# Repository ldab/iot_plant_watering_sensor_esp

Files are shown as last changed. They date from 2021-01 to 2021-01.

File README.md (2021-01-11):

# iot_plant_watering_sensor_esp32
Connected, IoT, WiFi capacitance plant watering sensor based on ESP32







 ## TODO

- [ ] Better battery polarity indication and reverse polarity protection;
- [ ] Fix R16 - R19 Silk
- [ ] R15 is leaking 200uA
- [ ] Check if `esp_light_sleep_start()` improves current vs `delay(x)`
- [ ] Inspect connection time if BSSID is saved vs Saving time
- [ ] FOTA
- [ ] Error reporting and callbacks, i.e FFAT, ADC read, etc..

## VOID

"Lorem ipsum dolor sit amet, consectetur adipiscing elit, sed do eiusmod tempor incididunt ut labore et dolore magna aliqua. Ut enim ad minim veniam, quis nostrud exercitation ullamco laboris nisi ut aliquip ex ea commodo consequat. Duis aute irure dolor in reprehenderit in voluptate velit esse cillum dolore eu fugiat nulla pariatur. Excepteur sint occaecat cupidatat non proident, sunt in culpa qui officia deserunt mollit anim id est laborum."

## Working modes and button

* The device will check the moisture 2x a day, at 8am and 6pm;
* On Sundays it will connect to the internet and check time, etc;
* Insert the battery **WATCH THE POLAITY**;
* Press and hold the `config` button;
  * keep it pressed, it will connect to the internet, get the time and date and calibrate the sensor;
  * if everything goes well, it buzzes like this [link for audio]()
* If the battery voltage is lower than 2V, an `email` will be sent and it buzzes like this [link for audio](./ringtones/urgent.mid)
* If the soil is drier than the setpoint, an `email` will be sent and it buzzes like this [link for audio]()
* If a new level of alarm is nedded, press and hold the config button until a buzz like this [link for audio]() is heard;

## Component selection and Capacitive probe

* We need the most range on the voltage across the probe as possible, considering
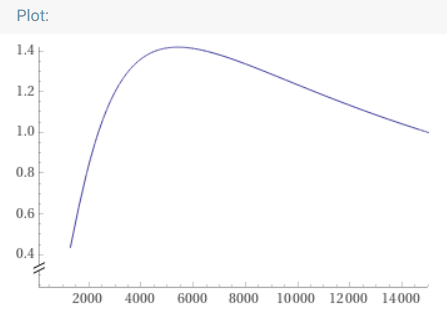
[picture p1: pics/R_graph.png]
    
    
**`Vc = 3 * (1 - e(-t / (R * C)))`**

* Varying R from 100 to 15000 Ω @ 1MHz:



[Wolfram Alpha - R Graph](https://www.wolframalpha.com/input/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)

* From the graph below we go with 5KΩ, the capacitance of the probe varies from 50pF to 200pF:

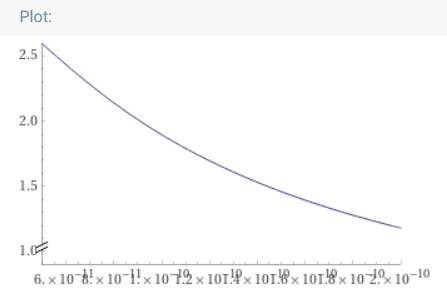
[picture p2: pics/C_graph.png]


[Wolfram Alpha - C Graph](https://www.wolframalpha.com/input/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)

* With a voltage range of 2.6 to 1.2 **~1.4V**.

## Capacitive sensor measurement

* When in the air, the sensor measures ~2.67V @ 1666(adc)



* And below 1000 (adc) ~1.8V when wet soil/water



## PSEUDO-CODE

```
main()
{ 
  turn radio OFF;
  config pins;

  read RTC();

  if( dateIsNotSet )    // probably first time
  {
    beep 2x;
    connect to the internet;
    set date;
    config RTC;
  }

  read moisture;

  if( alarmIsNotActive ) // wake from button
  {
    beep 5x;
    set new moisture level;
    clear alarm flag;    // aka sleep
  }
  else
  {
    if( moisture < threshould)
    {
      connect to the internet;
      send email/MQTT;
      turn radio OFF;

      while( times )
      {
        chrip
      }

      wake 
      clear alarm flag;    // aka sleep
    }
    else
    {
      clear alarm flag;    // aka sleep
    }
  }

  printf should never get here
} 
```

## Power Profile

* The DHCP negotiation and IP assignment can take a long time depending on the router, the below example is from a fairly long avg 90mA@2.8V for 3 s -> Includes ADC reading and MQTT publish

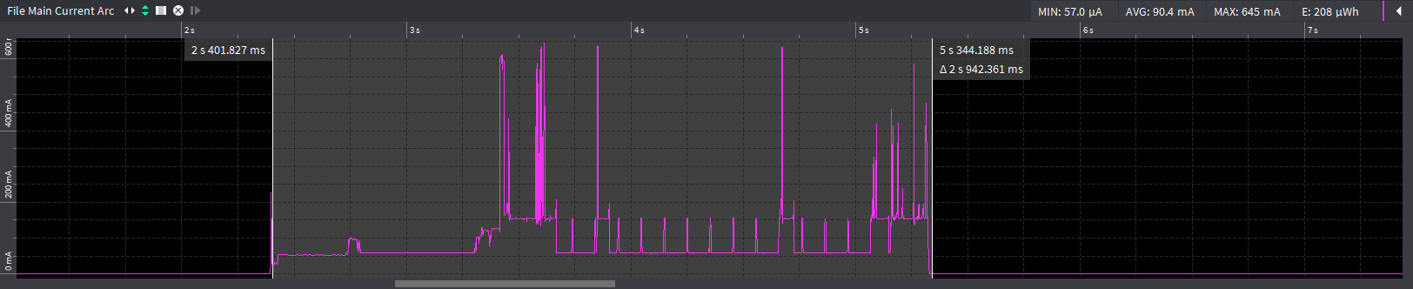
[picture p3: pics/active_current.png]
 

* When not connecting to WiFi, it is a lot faster:

 

* And during sleep 6uA@2.8V maninly due to the battery ADC (VCC/1MOhm =~ 3uA) and Boost disabled, ~1uA

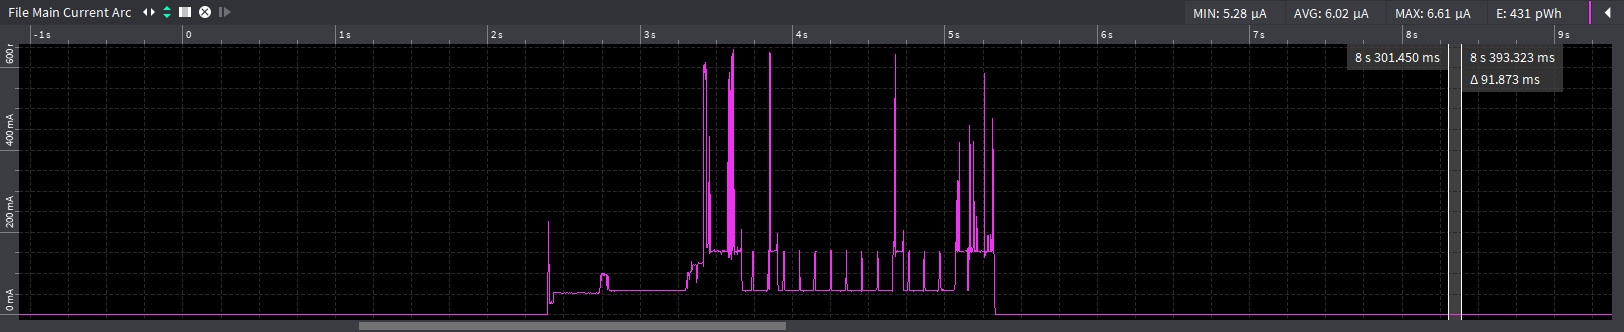
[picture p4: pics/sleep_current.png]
 

* Primary battery CR-2 drops a bit during active, 280mv:

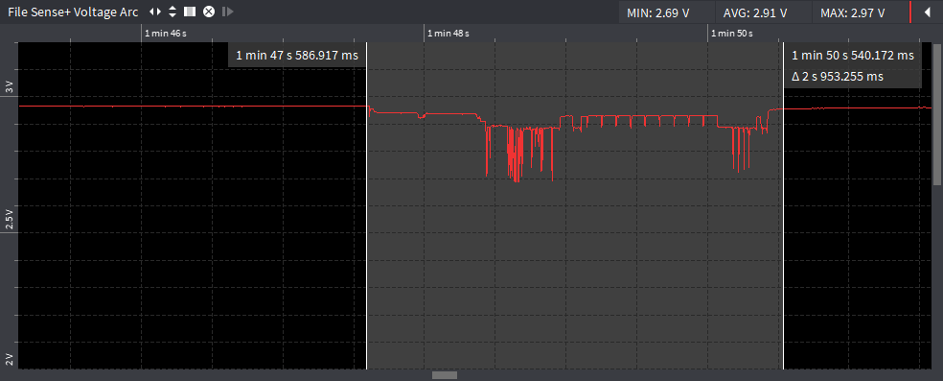
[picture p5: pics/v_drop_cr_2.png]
 

## Calibrating ADC for ESP32

* ADC on ESP32 has been reported being innacurate, therefore one can use ```adc2_vref_to_gpio( GPIO_NUM_25 );``` to route `Vref` to `GPIO_NUM_25` that can be measured over `ESP32 pin 10` in order to calibrate during ADC measurement.
* Calling for `esp_adc_cal_characterize(ADC_UNIT_1, ADC_ATTEN_DB_6, ADC_WIDTH_BIT_11, Vref, adc_chars);`

https://docs.espressif.com/projects/esp-idf/zh_CN/latest/esp32/api-reference/peripherals/adc.html

## FFat and time

```
  [641] IP address: 192.168.0.22
  Contacting Time Server
  [854] Now is : 2020-11-27T16:37:33
  Writing file: /hello.txt
  File written
  [1030] DONE writing, took: 176ms
  Reading file: /hello.txt
  Read from file: 2020-11-27T16:37:33
  [1093] DONE reading, took: 5ms
```

## Schematic

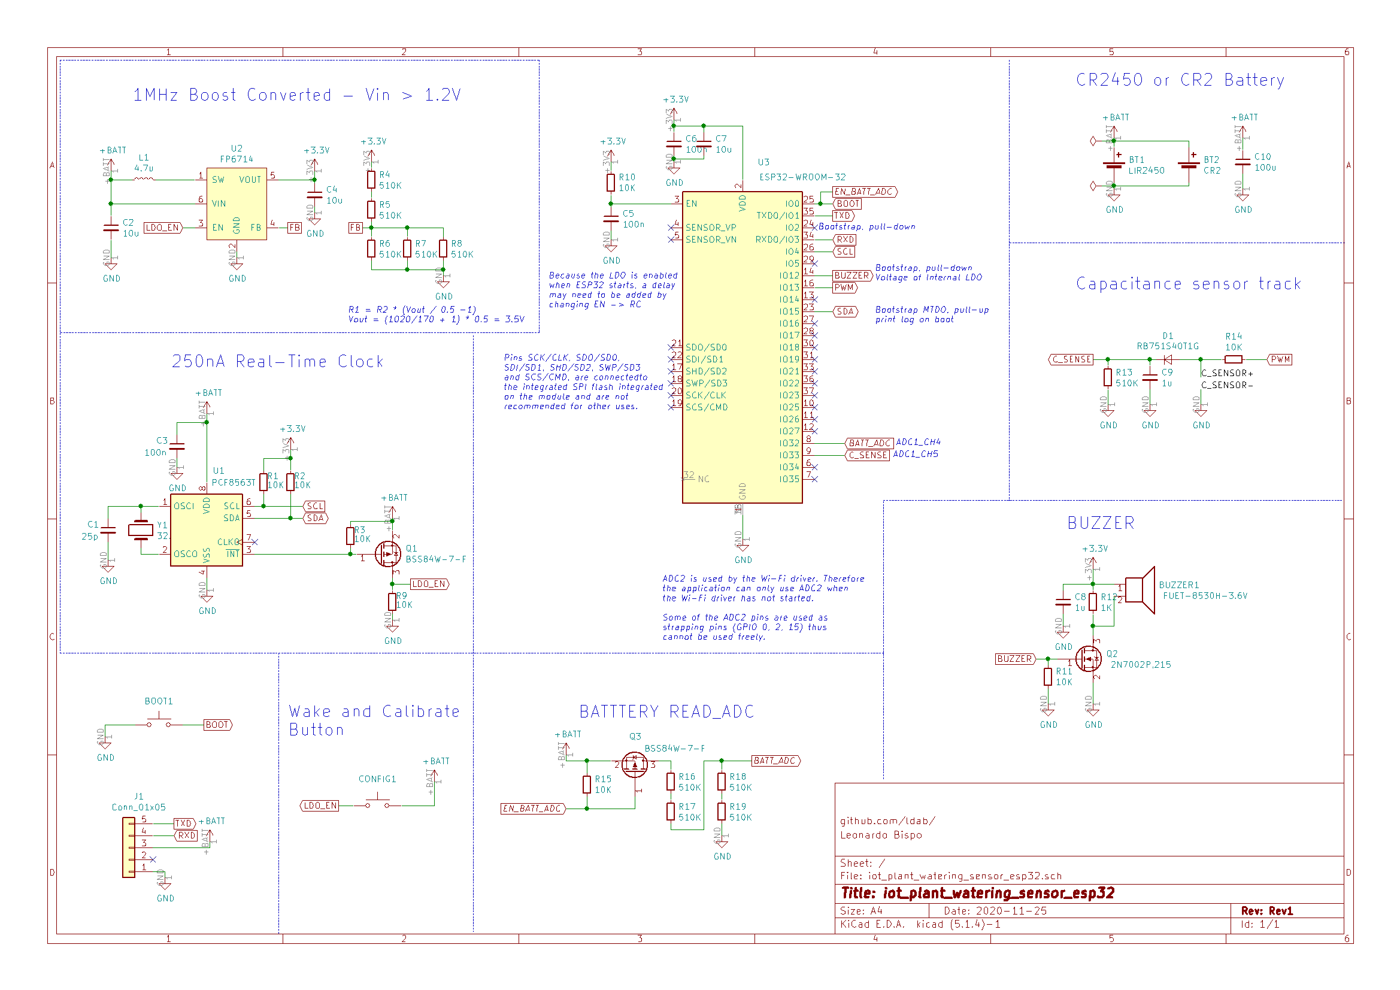
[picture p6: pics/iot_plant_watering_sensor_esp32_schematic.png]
 

## PCB

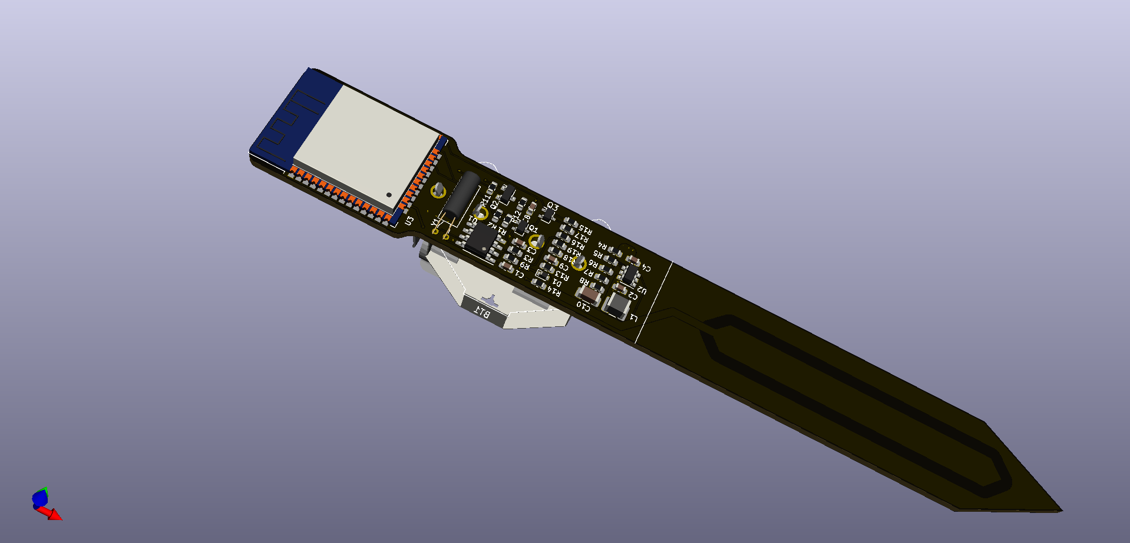
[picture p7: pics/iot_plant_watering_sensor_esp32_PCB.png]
 

## Enclosure

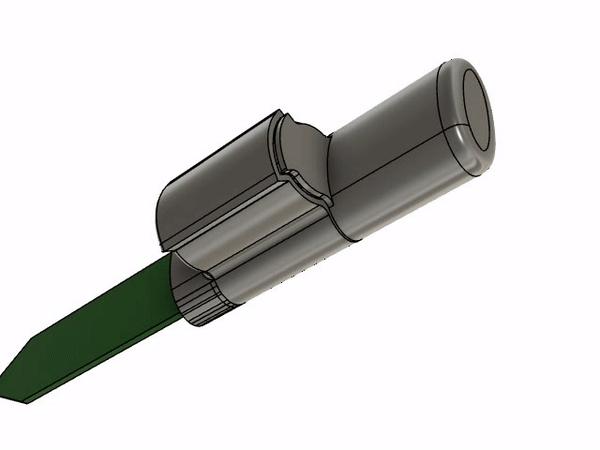
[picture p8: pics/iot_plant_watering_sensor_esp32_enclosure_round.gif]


## Known Limitations

* 

## Credits

Github Shields and Badges created with [Shields.io](https://github.com/badges/shields/)

Inspired by [chirp! - the plant watering alarm](https://wemakethings.net/chirp/)

ESP32 Pin definition and overview https://randomnerdtutorials.com/esp32-pinout-reference-gpios/

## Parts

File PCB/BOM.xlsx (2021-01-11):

Quantity | Description(optional) | LCSC Part Number(optional) | Package(optional) | Customer Part Number(optional)
2 | Push button switch, generic, two pins | C128941 | SamacSys_Parts:SW_Push_1P1T_NO_CK_KMR2 | > BOOT1, CONFIG1
1 | Single-cell battery | C238100 | Battery:BatteryHolder_Keystone_3008_1x2450 | BT1
1 | Single-cell battery | C238092 | custom:2915_CR2 | BT2
1 | Speaker | C417429 | Buzzer_Beeper:PUIAudio_SMT_0825_S_4_R | BUZZER1
1 | Unpolarized capacitor, small symbol | C282067 | Capacitor_SMD:C_0603_1608Metric | C1
3 | Unpolarized capacitor, small symbol | C338036 | Capacitor_SMD:C_0603_1608Metric | > C3, C5, C6
3 | Unpolarized capacitor, small symbol | C87152 | Capacitor_SMD:C_0603_1608Metric | > C2, C4, C7
2 | Unpolarized capacitor, small symbol | C92759 | Capacitor_SMD:C_0603_1608Metric | > C8, C9
1 | Unpolarized capacitor, small symbol | C77085 | Capacitor_SMD:C_1206_3216Metric | C10
1 | Diode, small symbol | C232576 | Diode_SMD:D_SOD-523 | D1
1 | Generic connector, single row, 01x05, script generated (kicad-library-utils/schlib/autogen/connector/) | DNP | custom:PinHeader_1x05_P2.54mm_Snuggly | J1
1 | Inductor, small symbol | C90319 | Inductor_SMD:L_1210_3225Metric | L1
2 | -0.13A Id, -50V Vds, P-Channel MOSFET, SOT-23 | C110490 | Package_TO_SOT_SMD:SOT-323_SC-70 | > Q1, Q3
1 | 0.115A Id, 60V Vds, N-Channel MOSFET, SOT-23 | C81488 | Package_TO_SOT_SMD:SOT-23 | Q2
1 | Resistor, small symbol | C384295 | Resistor_SMD:R_0603_1608Metric | R12
10 | Resistor, small symbol | C23192 | Resistor_SMD:R_0603_1608Metric | > R4-R8, R13, R16-R19
8 | Resistor, small symbol | C15401 | Resistor_SMD:R_0603_1608Metric | > R1-R3, R9-R11, R14, R15
1 | Realtime Clock/Calendar I2C Interface, SOIC-8 | C7440 | Package_SO:SOIC-8_3.9x4.9mm_P1.27mm | U1
1 | High-Efficiency, 1-Celland 2-Cell Boost Converter | C389170 | Package_TO_SOT_SMD:SOT-23-6 | U2
1 | RF Module, ESP32-D0WDQ6 SoC, Wi-Fi 802.11b/g/n, Bluetooth, BLE, 32-bit, 2.7-3.6V, onboard antenna, SMD | C82899 | RF_Module:ESP32-WROOM-32 | U3
1 | Two pin crystal | C70695 | Crystal:Crystal_C38-LF_D3.0mm_L8.0mm_Horizontal | Y1

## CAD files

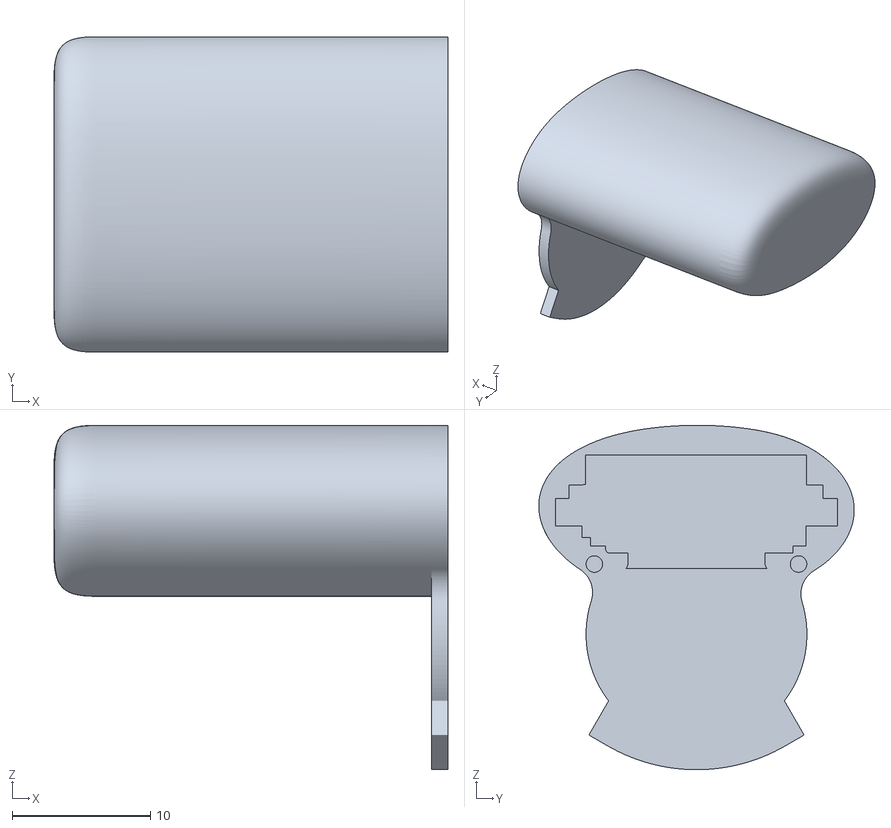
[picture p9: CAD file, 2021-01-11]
enclosure/iot_plant_watering_sensor_esp32_enclosure_top.stl
28.5 x 22.8 x 24.9

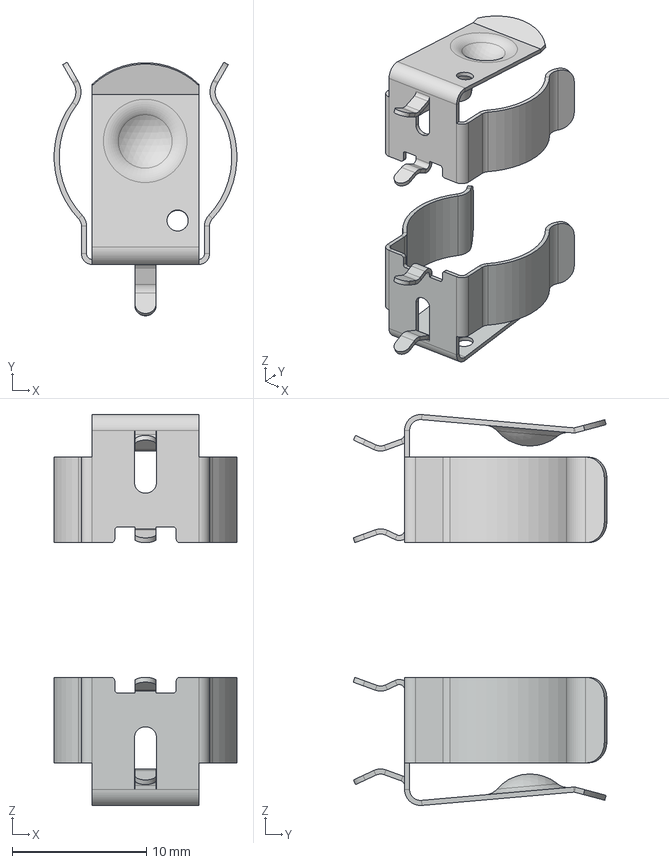
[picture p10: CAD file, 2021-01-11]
PCB/footprint_libs/keystone-PN2915_CR2.step
13.6 x 18.9 x 29.1 mm

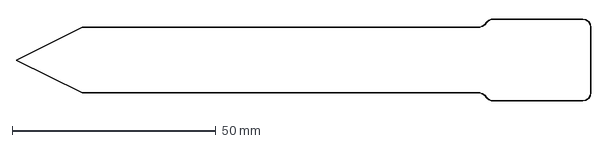
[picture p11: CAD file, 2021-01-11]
PCB/pcb.dxf
141.0 x 20.0 mm

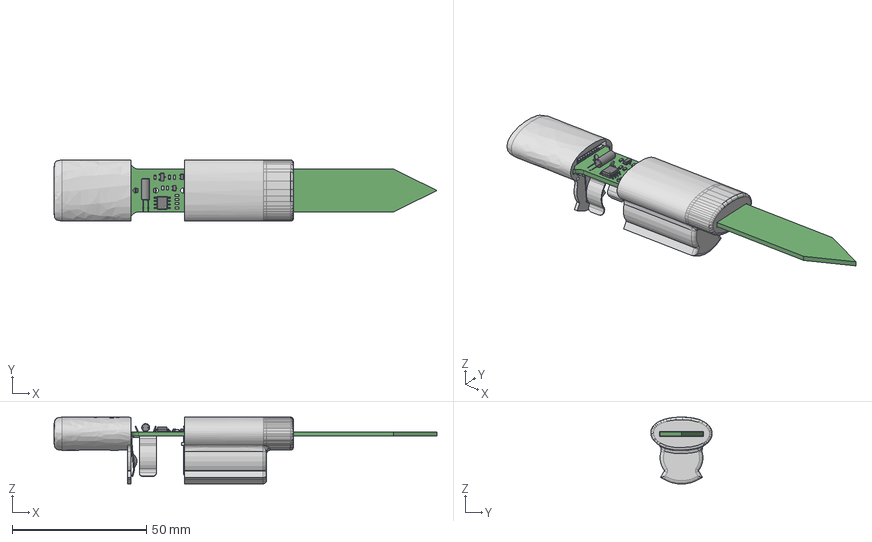
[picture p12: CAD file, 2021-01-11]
enclosure/iot_plant_watering_sensor_esp32_enclosure.step
142.4 x 22.8 x 24.9 mm
top
botton

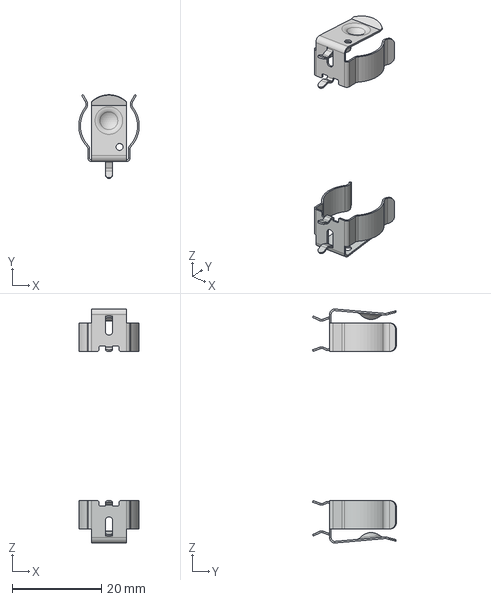
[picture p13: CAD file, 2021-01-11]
PCB/footprint_libs/keystone-PN2915_AA.STEP
13.6 x 18.9 x 52.6 mm

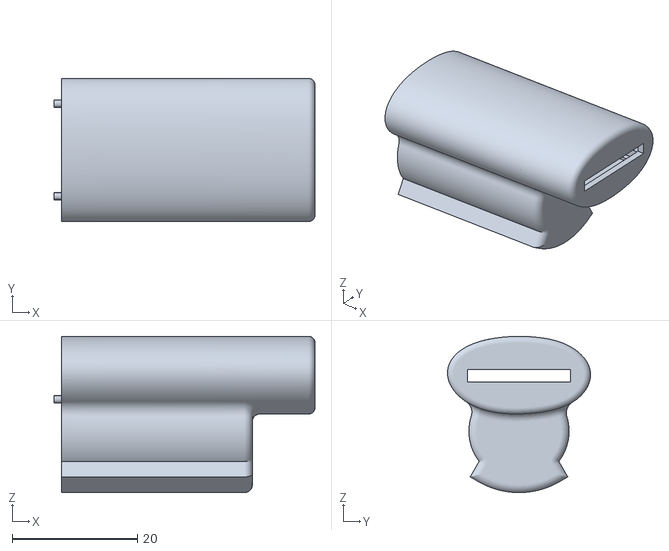
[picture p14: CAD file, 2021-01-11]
enclosure/iot_plant_watering_sensor_esp32_enclosure_bottom.stl
41.7 x 22.8 x 24.9

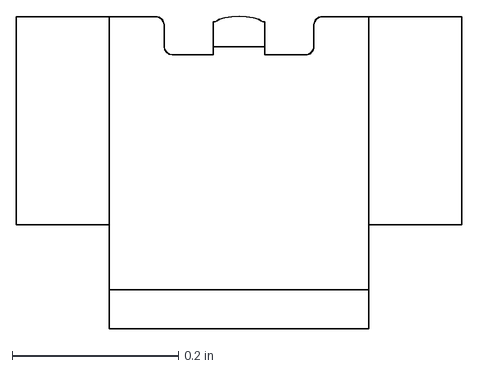
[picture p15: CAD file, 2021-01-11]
PCB/footprint_libs/2915.dxf
0.535 x 0.375 in

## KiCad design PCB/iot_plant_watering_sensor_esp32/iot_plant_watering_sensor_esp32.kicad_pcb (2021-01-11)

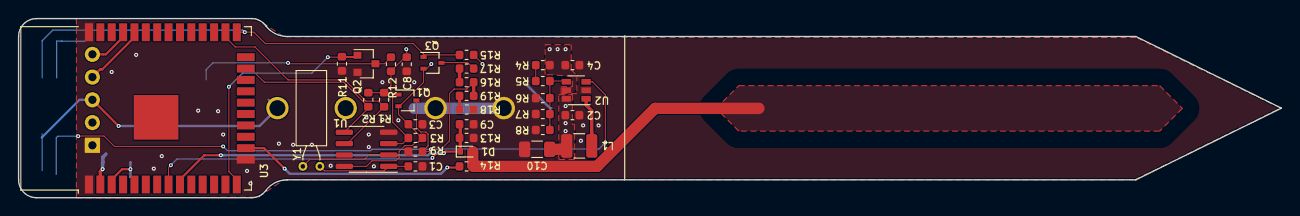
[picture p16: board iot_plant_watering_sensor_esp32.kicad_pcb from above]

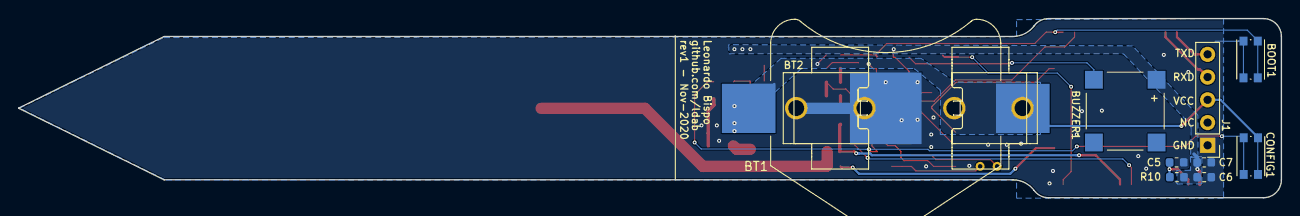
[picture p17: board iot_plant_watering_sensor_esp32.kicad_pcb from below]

Board: 2 copper layers, 141.0 x 20.0 mm, 44 parts (10 on the bottom side), 25 nets.

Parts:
BOOT1: SW_Push_KMR2; SW_Push_1P1T_NO_CK_KMR2
BT1: LIR2450; BatteryHolder_Keystone_3008_1x2450
BT2: CR2; 2915_CR2
BUZZER1: FUET-8530H-3.6V; PUIAudio_SMT_0825_S_4_R
C1: 25p; C_0603_1608Metric
C2, C4, C7: 10u; C_0603_1608Metric
C3, C5, C6: 100n; C_0603_1608Metric
C8, C9: 1u; C_0603_1608Metric
C10: 100u; C_1206_3216Metric
CONFIG1: SW_Push_KMR2; SW_Push_1P1T_NO_CK_KMR2
D1: RB751S40T1G; D_SOD-523
J1: Conn_01x05; PinHeader_1x05_P2.54mm_Snuggly
L1: 4.7u; L_1210_3225Metric
Q1, Q3: BSS84W-7-F; SOT-323_SC-70
Q2: 2N7002P,215; SOT-23
R1, R2, R3, R9, R10, R11, R14, R15: 10K; R_0603_1608Metric
R4, R5, R6, R7, R8, R13, R16, R17, R18, R19: 510K; R_0603_1608Metric
R12: 1K; R_0603_1608Metric
U1: PCF8563T; SOIC-8_3.9x4.9mm_P1.27mm
U2: FP6714; SOT-23-6
U3: ESP32-WROOM-32
Y1: 32.768 kHz; Crystal_C38-LF_D3.0mm_L8.0mm_Horizontal

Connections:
+3V3: BUZZER1.1, C4.1, C6.1, C7.1, C8.1, R1.2, R2.2, R4.1, R10.2, R12.1, U2.5, U3.2
+BATT: BT1.1, BT2.1, C2.1, C3.1, C10.1, CONFIG1.2, J1.3, L1.1, Q1.2, Q3.2, R3.2, R15.2, U1.8, U2.6
/C_SENSOR+: D1.2, R14.2
BATT_ADC: R17.2, R18.1, U3.8
BOOT: BOOT1.2, Q3.1, R15.1, U3.25
BUZZER: Q2.1, R11.2, U3.14
C_SENSE: C9.1, D1.1, R13.1, U3.9
FB: R5.2, R6.1, R7.1, R8.1, U2.4
GND: BOOT1.1, BT1.2, BT2.2, C1.2, C2.2, C3.2, C4.2, C5.2, C6.2, C7.2, C8.2, C9.2, C10.2, J1.1, Q2.2, R6.2, R7.2, R8.2, R9.1, R11.1, R13.2, R19.2, U1.4, U2.2, U3.1, U3.15, U3.38
LDO_EN: CONFIG1.1, Q1.3, R9.2, U2.3
unnamed: BUZZER1.2, Q2.3, R12.2
unnamed: C1.1, U1.1, Y1.1
unnamed: C5.1, R10.1, U3.3
unnamed: L1.2, U2.1
unnamed: Q1.1, R3.1, U1.3
unnamed: Q3.3, R16.1
unnamed: R4.2, R5.1
unnamed: R16.2, R17.1
unnamed: R18.2, R19.1
unnamed: U1.2, Y1.2
PWM: R14.1, U3.16
RXD: J1.4, U3.34
SCL: R1.1, U1.6, U3.26
SDA: R2.1, U1.5, U3.23
TXD: J1.5, U3.35

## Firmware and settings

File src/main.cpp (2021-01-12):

/******************************************************************************
main.cpp
Connected, IoT, WiFi capacitance plant watering sensor based on ESP32
Leonardo Bispo
Nov, 2020
https://github.com/ldab/iot_plant_watering_sensor_esp32
Distributed as-is; no warranty is given.
******************************************************************************/

#include <Arduino.h>
#include <Ticker.h>
#include <WiFi.h>
#include <Wire.h>
#include <driver/adc.h>
#include <esp_adc_cal.h>

#include "AsyncMqttClient.h"
#include "FFat.h"
#include "FS.h"
#include "RTClib.h"
#include "RTTTL.h"
#include "secrets.h"
#include "soc/rtc_cntl_reg.h"  //disable brownout
#include "soc/soc.h"           //disable brownout

#ifndef DEVICE_NAME
#error Remember to define the Device Name
#elif not defined TO
#error Remember to set the email address
#endif

#ifdef VERBOSE
#define DBG(msg, ...) \
  { Serial.printf("[%lu] " msg, millis(), ##__VA_ARGS__); }
#else
#define DBG(...)
#endif

#define VREF_CALIB 1098  // #define CALIBRATE and measure Vref

#define C_SENSE A5   // GPIO33 - IO33/ADC1_CH5
#define BATT_ADC A4  // GPIO32 - IO32/ADC1_CH4
#define BATT_EN A11  // GPIO0
#define PWM A14      // GPIO13
#define BUZZER A15   // GPIO12
#define SDA_PIN A13  // GPIO15
#define SCL_PIN A10  // GPIO04

#define PWM_CHANNEL 0
#define BUZZER_CHANNEL 1
#define PWM_FREQUENCY 1000000L  // 1MHz
#define BUZZER_FREQ 4000L

// Update these with values suitable for your network.
const char *wifi_ssid = s_wifi_ssid;
const char *wifi_password = s_wifi_password;
const char *mqtt_server = s_mqtt_server;
const char *mqtt_user = s_mqtt_user;
const char *mqtt_pass = s_mqtt_pass;
uint16_t mqtt_port = s_mqtt_port;

/*
{
    "to": "email",
    "state": "off",
    "attributes": {
        "friendly_name": "ESP_BANANA_moisture",
        "device_class": "moisture"
    }
}
*/

// initialize the MQTT Client
WiFiClient espClient;
AsyncMqttClient mqttClient;
bool published = false;

// RTC instance
RTC_PCF8563 rtc;

int16_t capSensorThrs = -1;
int16_t capSensorSense = -1;
char iso8601date[] = "2000-01-01T00:00:00";

void static chirp(uint8_t times);

void WiFiEvent(WiFiEvent_t event) {
  // DBG("[WiFi-event] event: %d\n", event);

  switch (event) {
    case SYSTEM_EVENT_STA_CONNECTED:
      DBG("Connected to access point\n");
      break;
    case SYSTEM_EVENT_STA_DISCONNECTED:
      DBG("Disconnected from WiFi access point\n");
      break;
    case SYSTEM_EVENT_STA_GOT_IP:
      DBG("Obtained IP address: ");
      Serial.println(WiFi.localIP());
      break;
    default:
      break;
  }
}

void setup_wifi() {
  delay(10);

  char id[32];
  sprintf(id, "%s-%s", DEVICE_NAME, WiFi.macAddress().c_str());
  DBG("Device name is %s\n", id);

  WiFi.onEvent(WiFiEvent);

  if (WiFi.SSID() != wifi_ssid) {
    DBG("Connecting to %s\n", wifi_ssid);

    WiFi.mode(WIFI_STA);
    WiFi.setAutoReconnect(true);  // TODO maybe false as WiFI should start off

    // int32_t wifi_channel = WiFi.channel();
    // uint8_t wifi_bssid[6]; //{0xF8, 0xD1, 0x11, 0x24, 0xB3, 0x84};

    // https://github.com/espressif/arduino-esp32/issues/2537
    WiFi.config(
        INADDR_NONE, INADDR_NONE,
        INADDR_NONE);  // call is only a workaround for bug in WiFi class

    // WiFi.begin(wifi_ssid, wifi_password, wifi_channel, wifi_bssid);
    WiFi.begin(wifi_ssid, wifi_password);

    WiFi.setHostname(id);

    WiFi.persistent(true);  // TODO maybe false as WiFI should start off
  }

  while (millis() < 10000)  // TODO
  {
    int8_t wifi_result = WiFi.waitForConnectResult();
    if (wifi_result == WL_CONNECTED) break;
    DBG(".");
  }
  if (WiFi.status() == WL_CONNECTED) {
    randomSeed(micros());

    mqttClient.setServer(mqtt_server, mqtt_port);
    mqttClient.setCredentials(mqtt_user, mqtt_pass);
    mqttClient.setClientId(id);
    DBG("Connecting to MQTT Server %s\n", mqtt_server);
    mqttClient.connect();
  } else {
    DBG(" WiFi connect failed: %d\n", WiFi.status());
    play(BUZZER_CHANNEL, Urgent, sizeof(Urgent) / sizeof(char *));
    esp_deep_sleep(360000000L);
  }

  while (!mqttClient.connected() && millis() < 10000) {
    delay(50);
  }
  if (!mqttClient.connected()) {
    DBG(" MQTT connect failed: %d\n", WiFi.status());
    play(BUZZER_CHANNEL, Urgent, sizeof(Urgent) / sizeof(char *));
    esp_deep_sleep(360000000L);
  }
}

void onMqttConnect(bool sessionPresent) { DBG("Connected to MQTT\n"); }

void onMqttPublish(uint16_t packetId) {
  DBG("Publish acknowledged.\n");
  published = true;
}

void send_error(String problem) {
  char
      topic[strlen("/states/binary_sensor._problem") + strlen(DEVICE_NAME) + 1];
  snprintf(topic, sizeof(topic), "/states/binary_sensor.%s_problem",
           DEVICE_NAME);

  char payload[160];
  snprintf(payload, sizeof(payload),
           "{\"to\": \"%s\",\"state\": \"on\",\"attributes\": "
           "{\"friendly_name\": \"%s_problem\",\"device_class\": "
           "\"problem\",\"problem_string\": \"%s\"}}",
           TO, DEVICE_NAME, problem.c_str());

  // client.publish(topic, payload);
  mqttClient.publish(topic, 2, false, payload);
}

void inline static beep() {
  ledcWriteTone(BUZZER_CHANNEL,
                BUZZER_FREQ);  // Set res to 10 bits and call ledcWrite();

  delay(42);

  ledcWriteTone(BUZZER_CHANNEL, 0);
}

void static chirp(uint8_t times) {
  /* TODO
  // radio off to save power
  btStop();
  WiFi.mode( WIFI_OFF );

  //ligth sleep 0.8mA
  https://lastminuteengineers.com/esp32-sleep-modes-power-consumption/
  esp_sleep_enable_timer_wakeup( 666 );
  esp_light_sleep_start();
  */

  while (times-- > 0) {
    beep();
    delay(40);
  }
}

int16_t read_moisture() {
  int16_t _adc;

  ledcSetup(PWM_CHANNEL, PWM_FREQUENCY, 1);  // ADC res depends on freq, 1b@50%
  ledcWrite(PWM_CHANNEL, 1);

  delay(250);  // 50ms is probably enough, play safe, check pics

  ledcWrite(PWM_CHANNEL, 0);

  esp_adc_cal_characteristics_t *adc_chars = new esp_adc_cal_characteristics_t;
  esp_adc_cal_characterize(ADC_UNIT_1, ADC_ATTEN_DB_11, ADC_WIDTH_BIT_11,
                           VREF_CALIB, adc_chars);

  _adc = adc1_get_raw(ADC1_CHANNEL_5);
  uint32_t cap_milli = esp_adc_cal_raw_to_voltage(_adc, adc_chars);

  DBG("Read ADC for capacitive sensor: %d or %dmV\n", _adc, cap_milli);

  return _adc;
}

void getInternetTime() {
  uint8_t timezone = 1;
  uint8_t daysavetime = 1;

  configTime(3600 * timezone, daysavetime * 3600, "dk.pool.ntp.org",
             "0.pool.ntp.org", "1.pool.ntp.org");
  struct tm tmstruct;
  tmstruct.tm_year = 0;
  getLocalTime(&tmstruct, 2000);
  sprintf(iso8601date, "%d-%02d-%02dT%02d:%02d:%02d\n",
          (tmstruct.tm_year) + 1900, (tmstruct.tm_mon) + 1, tmstruct.tm_mday,
          tmstruct.tm_hour, tmstruct.tm_min, tmstruct.tm_sec);
  DBG("NTP time : %s\n", iso8601date);
}

void pinInit() {
  pinMode(BATT_EN, OUTPUT);
  digitalWrite(BATT_EN, HIGH);

  ledcAttachPin(PWM, PWM_CHANNEL);

  ledcAttachPin(BUZZER, BUZZER_CHANNEL);

  adc1_config_width(ADC_WIDTH_BIT_11);  // Reduce ADC resolution due to reported
                                        // noise on 12 bits
  adc1_config_channel_atten(
      ADC1_CHANNEL_5, ADC_ATTEN_DB_11);  // 11dB attenuation (ADC_ATTEN_DB_11)
                                         // gives full-scale voltage 3.5V
  adc1_config_channel_atten(
      ADC1_CHANNEL_4, ADC_ATTEN_DB_6);  // 6dB attenuation (ADC_ATTEN_DB_6)
                                        // gives full-scale voltage 2.2V
}

uint16_t getBattmilliVcc() {
  digitalWrite(BATT_EN, LOW);

  esp_adc_cal_characteristics_t *adc_chars = new esp_adc_cal_characteristics_t;
  esp_adc_cal_characterize(ADC_UNIT_1, ADC_ATTEN_DB_6, ADC_WIDTH_BIT_11,
                           VREF_CALIB, adc_chars);

  uint32_t raw = adc1_get_raw(ADC1_CHANNEL_4);  // analogRead(BATT_ADC);
  uint32_t battmilliVcc = esp_adc_cal_raw_to_voltage(raw, adc_chars) * 2;

  DBG("Measure ADC Battery, raw: %d, %dmV\n", raw, battmilliVcc);

  digitalWrite(BATT_EN, HIGH);

  return battmilliVcc;
}

void rtc_init() {
  DBG("RTC init\n");

  Wire.begin(SDA_PIN, SCL_PIN, 100000L);
  if (!rtc.begin()) {
    DBG("Couldn't find RTC\n");
    chirp(3);
    // send_error("RTC"); TODO
  }

  // Disable CLKOUT @ 200nA vs 550nA when active
  rtc.writeSqwPinMode(PCF8563_SquareWaveOFF);

  // When the RTC was stopped and stays connected to the battery, it has
  // to be restarted by clearing the STOP bit. Let's do this to ensure
  // the RTC is running.
  rtc.start();
}

void powerOff(DateTime now) {
  WiFi.disconnect(true);  // TODO check if false changes time

  DBG("Now is : %d/%d/%dT%d:%d\n", now.year(), now.month(), now.day(),
      now.hour(), now.minute());

  if (now.hour() >= 18) {
    DBG("Set wake to 8AM\n");
    rtc.setAlarm(8, 00);
  } else {
    DBG("Set wake to 6PM\n");
    rtc.setAlarm(18, 00);
  }

  DBG("Clear alarm flag, disabling LDO\n");

  rtc.clearAlarm();
}

int16_t readThreshold(void) {
  const char *path = "/threshold.txt";

  DBG("Reading file: %s\r\n", path);

  File file = FFat.open(path);
  if (!file || file.isDirectory()) {
    DBG("- failed to open file for reading\n");
    // send_error("FFAT read"); TODO
    return -2;
  }

  DBG("Read from file: ");

  uint8_t i = 0;
  char t[5] = "";

  while (file.available()) {
    t[i] = file.read();
    DBG("%c", t[i]);
    i++;
  }
  DBG("\n");

  file.close();

  return atoi(t);
}

void writeThreshold(int16_t _t) {
  const char *path = "/threshold.txt";

  DBG("Writing file: %s\n", path);

  File file = FFat.open(path, FILE_WRITE);
  if (!file) {
    DBG("Failed to open file for writing\n");
    // send_error("FFAT write"); TODO
    return;
  }
  if (file.print(_t)) {
    DBG("File written\n");
  } else {
    DBG("Write failed\n");
  }
  file.close();
}

void setup() {
#ifdef VERBOSE
  Serial.begin(115200);
#endif

#ifdef CALIBRATE
  // Measure GPIO in order to determine Vref to gpio 25 or 26 or 27
  adc2_vref_to_gpio(GPIO_NUM_25);
  delay(5000);
  abort();
#endif

  WRITE_PERI_REG(RTC_CNTL_BROWN_OUT_REG, 0);  // disable brownout detector

  pinInit();

  mqttClient.onConnect(onMqttConnect);
  mqttClient.onPublish(onMqttPublish);

  if (!FFat.begin(true)) {
    DBG("FFat Mount Failed\n");
    chirp(1);
    delay(100);
    chirp(1);
    delay(100);
    chirp(1);
    delay(100);
    // send_error("FFat mount"); TODO
  }
  DBG("Total space: %10u\n", FFat.totalBytes());
  DBG("Free space: %10u\n", FFat.freeBytes());

  rtc_init();

  DateTime now = rtc.now();
  DBG("RTC date is: %d-%d-%dT%d:%d:%d\n", now.year(), now.month(), now.day(),
      now.hour(), now.minute(), now.second());

  if (rtc.lostPower() || now.dayOfTheWeek() == 0) {
    DBG("RTC is NOT initialized, let's set the time!\n");
    DBG("OR is Sunday!\n");
    setup_wifi();
    getInternetTime();
    rtc.adjust(DateTime(iso8601date));

    now = rtc.now();
  }

  if (!rtc.alarmFired())  // Interrupt from button, wait and confirm
  {
    chirp(2);
    DBG("CFG Button pressed, wait 2 sec\n");

    // only wait for the button press if reaches here quickly
    // otherwise it'd indicates internet connection
    if (millis() < 1000) {
      esp_sleep_enable_timer_wakeup(2000000L);
      esp_light_sleep_start();
    }

    if (!rtc.alarmFired())  // sanity check -> if button is released, power OFF
    {
      chirp(2);
      capSensorSense = read_moisture();
      writeThreshold(capSensorSense);

      setup_wifi();
      getInternetTime();
      rtc.adjust(DateTime(iso8601date));
      now = rtc.now();

      play(BUZZER_CHANNEL, Skala, sizeof(Skala) / sizeof(char *));
      powerOff(now);

      // if button is kept pressed, sleep
      esp_sleep_enable_timer_wakeup(2000000L);
      esp_light_sleep_start();
      // esp_deep_sleep_start();
    }
  }

  uint16_t batt = getBattmilliVcc();
  capSensorThrs = readThreshold();
  capSensorSense = read_moisture();

#ifdef VERBOSE
  setup_wifi();

  uint8_t reset_reason = esp_reset_reason();

  char p[160];
  snprintf(p, sizeof(p),
           "{\"batt\": %d, \"adc\": %d, \"thr\": %d, \"time\": \"%s\", "
           "\"rssi\": %d, "
           "\"reset\": %d}",
           batt, capSensorSense, capSensorThrs, now.timestamp().c_str(),
           WiFi.RSSI(), reset_reason);

  char topic[strlen("/states/binary_sensor._debug") + strlen(DEVICE_NAME) + 1];
  snprintf(topic, sizeof(topic), "/states/binary_sensor.%s_debug", DEVICE_NAME);

  mqttClient.publish(topic, 2, false, p);

  while (published == false && millis() < 10000L) {
    delay(50);
  }
  published = false;
#endif

  DBG("Threshold is %d\n", capSensorThrs);

  // high is dry
  if (capSensorSense > capSensorThrs) {
    setup_wifi();

    DBG("DRY\n");

    // play(BUZZER_CHANNEL, Urgent);

    chirp(9);
    delay(350);
    chirp(1);
    delay(50);
    chirp(1);

    // HA-> on means moisture detected (wet), off means no moisture (dry)
    char topic[strlen("/states/binary_sensor._moisture") + strlen(DEVICE_NAME) +
               1];
    snprintf(topic, sizeof(topic), "/states/binary_sensor.%s_moisture",
             DEVICE_NAME);

    char payload[160];
    snprintf(
        payload, sizeof(payload),
        "{\"to\": \"%s\",\"state\": \"off\",\"attributes\": "
        "{\"friendly_name\": \"%s_moisture\",\"device_class\": \"moisture\"}}",
        TO, DEVICE_NAME);

    mqttClient.publish(topic, 2, false, payload);

    while (published == false && millis() < 10000L) {
      delay(50);
    }
    published = false;
  } else if (batt < 2200) {  // https://data.energizer.com/PDFs/CR2_EU.pdf
    DBG("Low battery\n");

    setup_wifi();

    chirp(3);
    delay(350);
    chirp(2);
    delay(50);
    chirp(1);

    // Home Assistant -> on means low, off means normal
    char topic[strlen("/states/binary_sensor._batt") + strlen(DEVICE_NAME) + 1];
    snprintf(topic, sizeof(topic), "/states/binary_sensor.%s_batt",
             DEVICE_NAME);

    char payload[160] = "";
    snprintf(payload, sizeof(payload),
             "{\"to\": \"%s\",\"state\": \"on\",\"attributes\": "
             "{\"friendly_name\": \"%s_batt\",\"device_class\": \"battery\"}}",
             TO, DEVICE_NAME);

    mqttClient.publish(topic, 2, false, payload);

    while (published == false && millis() < 10000L) {
      delay(50);
    }
  }

  powerOff(now);

  DBG("Should never get here\n");
}

void loop() {
  DateTime now = rtc.now();
  powerOff(now);
  // abort();
  esp_deep_sleep(120000000L);
}

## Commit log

2021-01-11 Async mqtt (#1)
    * initial comit
    * schematic and PIN definition
    * RTC and pinInit
    * pcb release
    * Merge branch 'dev' of https://github.com/ldab/iot_plant_watering_sensor_esp32 into dev
    * NTP
    * MQTT topics
    * 5uA sleep current -> dev drop
    * batt ADC fix
    * CR-2 batt voltage meas
    * fix PWM call, 10 bits stuff and def
    * new partition, allow OTA
    * disable brownout detector
    * 250ms delay for cap ADC
    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
    [2915.dxf, BOM.xlsx, Book1.xlsx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]
2021-01-11 power graph
2021-01-12 Ffat partition breaks
    [min_ffat.csv]

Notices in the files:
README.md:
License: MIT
